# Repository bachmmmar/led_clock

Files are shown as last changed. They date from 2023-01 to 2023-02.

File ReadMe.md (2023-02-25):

This project builds a Clock with RGB LED's araged on a large circle showing current time.
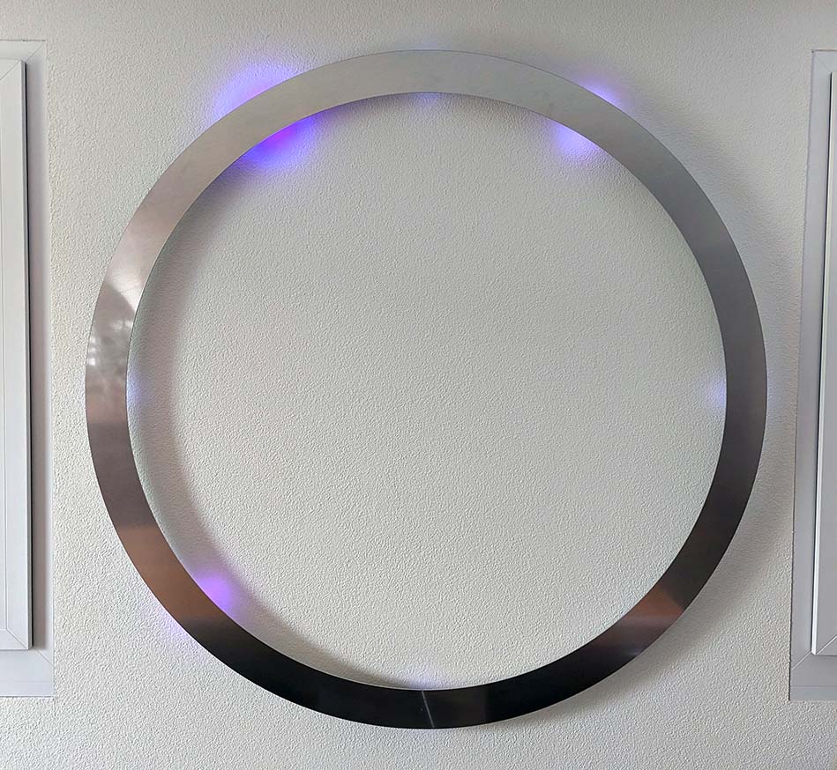
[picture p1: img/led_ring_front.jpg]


Clock showing 10:05 and 36 seconds.

It uses an Arduino Nano with Real Time Clock (RTC) and WS2811/WS2812 LED strip to display time. Ambient light sensor helps to have the right light during daytime or night.

# Overview
The images below show the main parts of the system.

| Button Mounted | Top View of Circuit | Side View of circuit |
| --- | --- | --- |
|  |  |  |

## Circuit
The following circuit was drawn with Fritzing and is located in [`circuit/led_clock.fzz`](./circuit/led_clock.fzz) folder. 
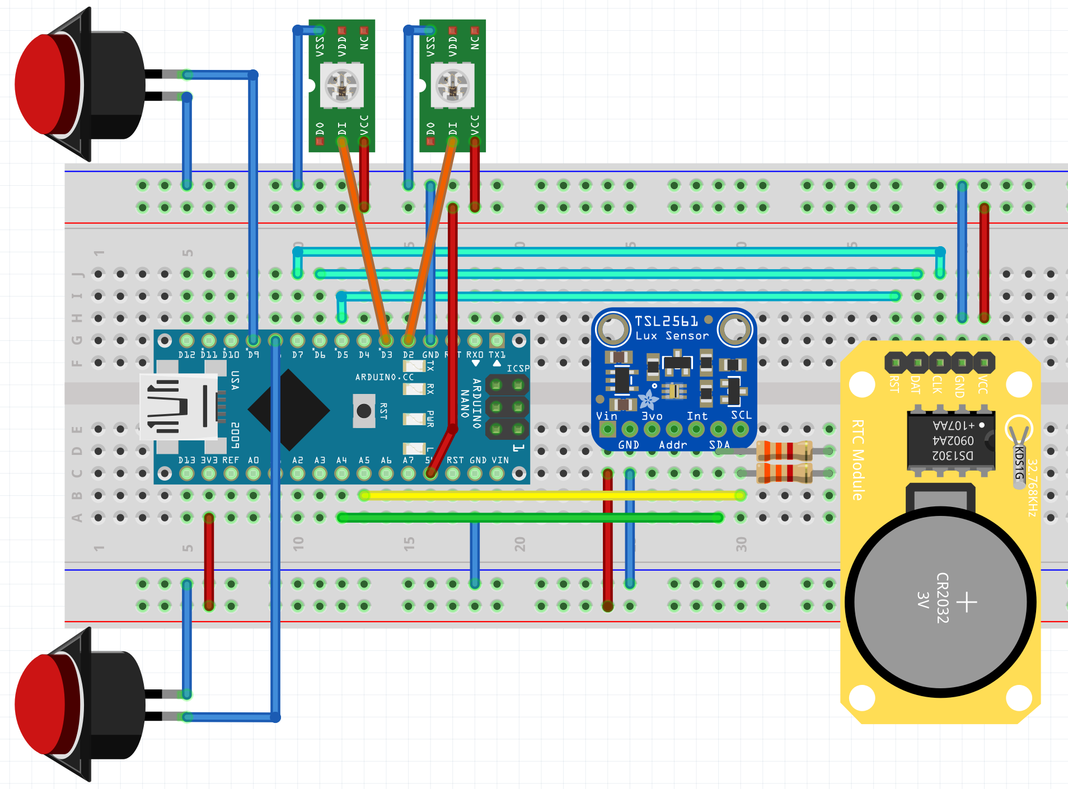
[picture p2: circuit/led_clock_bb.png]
breadboard circuit


## Mechanical Components
| Item | Supplier - Partnumber | Image | Details |
| ---  | --- | --- | --- |
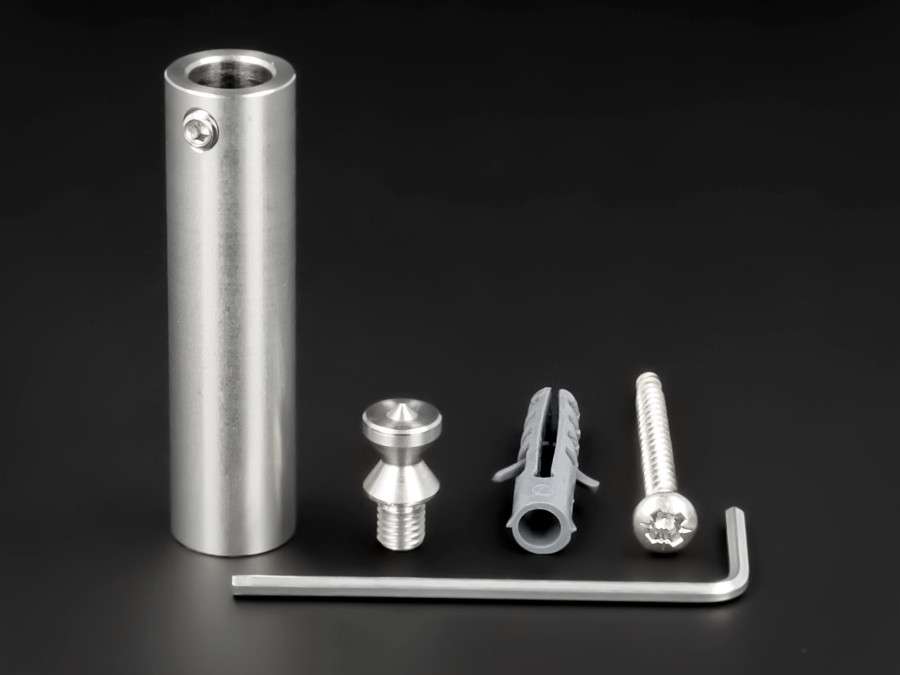
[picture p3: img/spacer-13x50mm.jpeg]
| Spacer for wall mounting | abstandshalter.com - 1.100.536 (50mm) |  | [Link](https://www.abstandshalter.com/wandabstandshalter/buchstabenbefestigung/schriften-befestigung-gewinde-edelstahl-oe-13x50mm-distanzhuelse-v2a) |
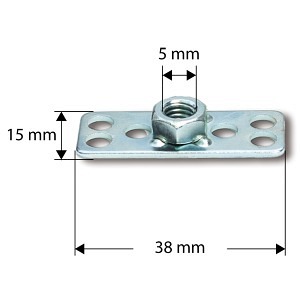
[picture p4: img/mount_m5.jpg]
| Composite mounting | Suter Kunststoffe AG - 491.5203 (15x38mm, M5) |  | [Link](https://shop.swiss-composite.ch/pi.php/Formenbau/Composite-Muttern-Schrauben/Composite-Mutter-INOX-M-5-38x15mm-pStk.html) |

## Electrical Components
| Item | Supplier - Partnumber | Image | Details |
| ---  | --- | --- | --- |
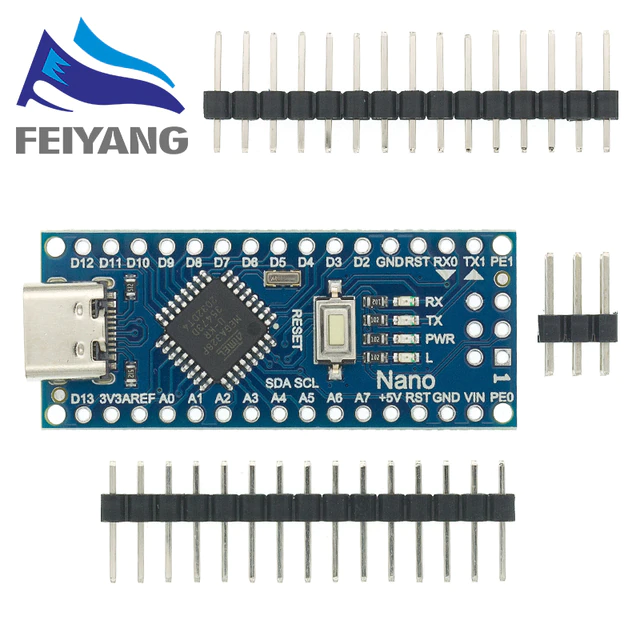
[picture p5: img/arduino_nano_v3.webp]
| Arduino Nano | Aliexpress - Arduino Nano V3.0 (ATmega328) |  | [Datasheet](datasheet/NanoV3.0_ATmega328_ali.pdf) |
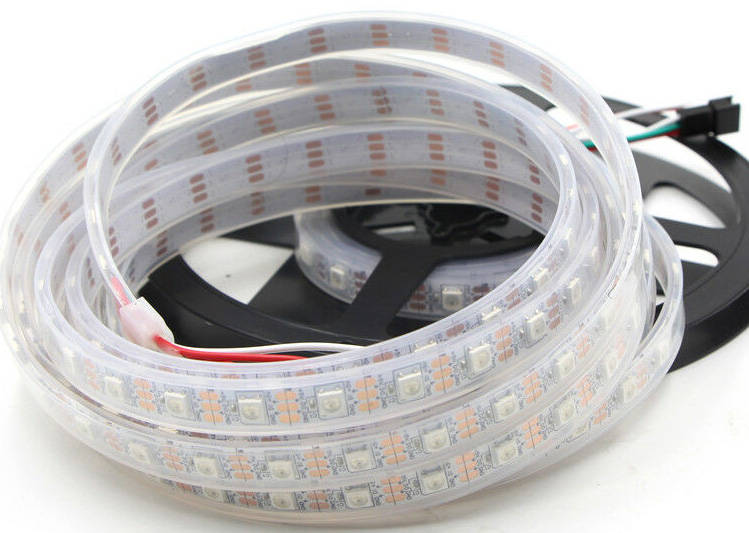
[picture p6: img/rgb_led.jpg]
| LED Stip | Aliexpress - "1m 2m 4m 5m WS2812B Led Lights WS2812 RGB Led Strip Light Individually Addressable Led Light Strip" |  | [Datasheet](datasheet/led_WS2812B.pdf)
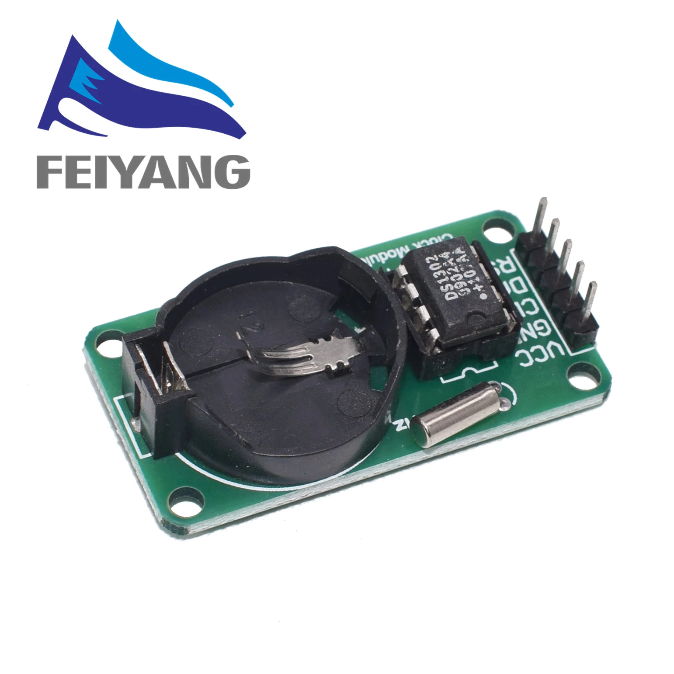
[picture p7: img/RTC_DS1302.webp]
| RTC DS1302 | Aliexpress - "RTC DS1302 Real Time Clock Modul for Arduino" |  | -
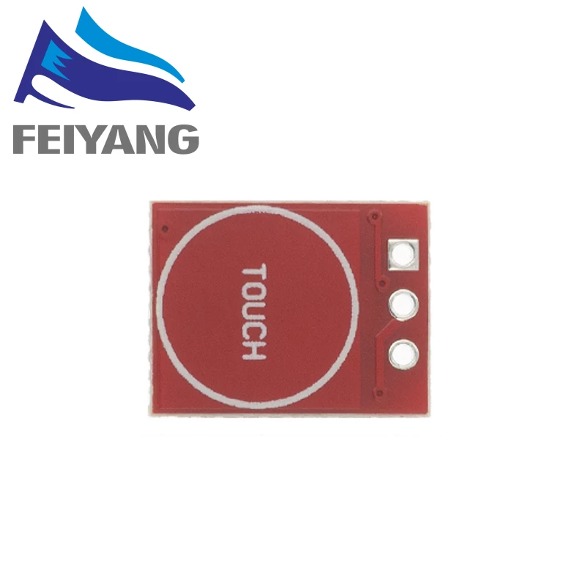
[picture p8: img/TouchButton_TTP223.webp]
| Button TTP223 | Aliexpress - "TTP223 Touch Key / Touching Button Module" |  | -
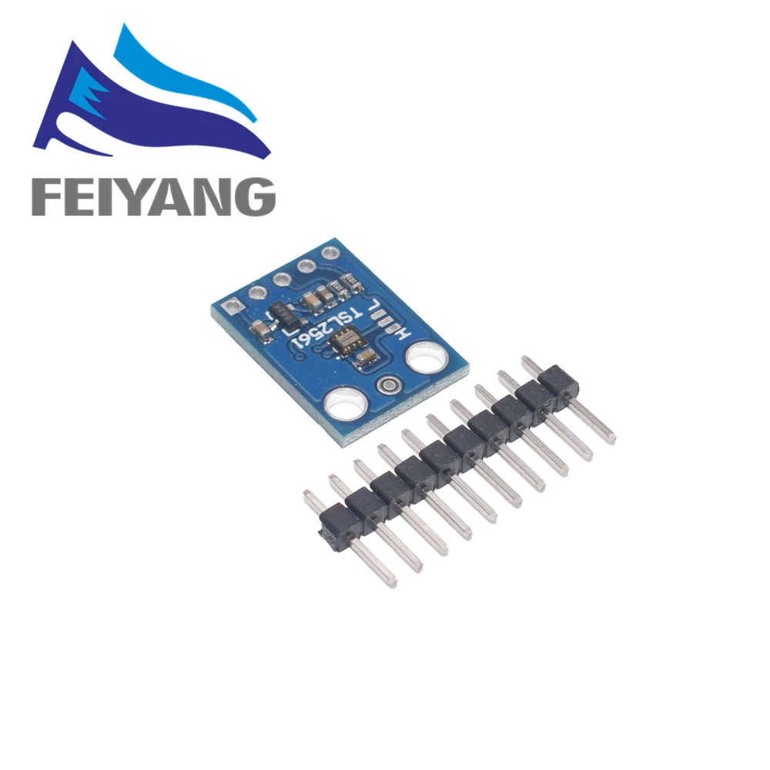
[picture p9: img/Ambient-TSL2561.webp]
| Ambient Sensor TSL2561 | Aliexpress - "GY-2561 TSL2561 Light Sensor Breakout Infrared Light Sensor Module" |  | -

## Code
The project can be compiled by using the [Arduino App](https://www.arduino.cc/download) or by using 
[CLion](https://www.jetbrains.com/clion/). This is why the project folder contains all the CMake files.

### Libraries
For controlling the LEDs, communicating with the RTC or getting ambient light the following libraries are used:
 - [TSL2561 Light Sensor](https://github.com/adafruit/TSL2561-Arduino-Library)
 - [DS1302 RTC](https://github.com/msparks/arduino-ds1302)
 - [WS2812B RGB LED](https://github.com/adafruit/Adafruit_NeoPixel)
 
 All libraries are directly located in the `src/` directory.
 
### Time Compesation
As my arduino has a verry inaccurate clock, the millis function return the wrong values.
In my case one minute tages 36'733 millis instead of 60000.
I need to multiply all millis() by 1.63

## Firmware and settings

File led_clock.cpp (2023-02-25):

#include <Arduino.h>
#include "src/clock.h"
#include "src/leds.h"
#include "src/ambient.h"


#define BUTTON_HOURS_PIN 8
#define BUTTON_MINUTE_PIN 9


Logger logger;
ClockConfig_t clk_cfg = {5, 6, 7};
Clock clk(&clk_cfg, &logger);
LedConfig_t led_cfg = {.inner_ring_pin=3, .outer_ring_pin=4,
                       .inner_ring_num_leds=229, .outer_ring_num_leds=252};
Leds led(&led_cfg, &logger);

LightSensorConfig_t light_cfg = {.tsl_i2c_addr=0x39, .update_time_ms=5000,
                                 .integration_time=TSL2561_INTEGRATIONTIME_101MS};
Ambient ambient(&light_cfg, &logger);


bool hour_pin_state, minute_pin_state;


bool isHourPinPressed() {
    return static_cast<bool>(digitalRead(BUTTON_HOURS_PIN));
}

bool isMinutePinPressed() {
    return static_cast<bool>(digitalRead(BUTTON_MINUTE_PIN));
}



/** Arduino setup function */
void setup() {
    logger.setup();
    logger.log(Logger::INFO, "Starting up clock...");

    // Configure Button Pin as input
    pinMode(BUTTON_MINUTE_PIN, INPUT_PULLUP);
    pinMode(BUTTON_HOURS_PIN, INPUT_PULLUP);

    hour_pin_state = isHourPinPressed();
    minute_pin_state = isMinutePinPressed();

    clk.setup();
    led.setup();
    ambient.setup();
}


/** Arduino loop function */
void loop() {
    clk.update();

    if (isHourPinPressed() && !hour_pin_state) {
        clk.incrementHours();
    }
    else if (isMinutePinPressed() && !minute_pin_state) {
        clk.incrementMinutes();
    }

    hour_pin_state = isHourPinPressed();
    minute_pin_state = isMinutePinPressed();

    if (ambient.update()) {
        led.updateBrightness(ambient.brightness_lux);
    }
    led.update(clk.current_time, clk.milliseconds_in_minute);
}

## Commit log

2023-01-21 Mechanical components documented and circuit drawn
    [led_clock.fzz]
2023-01-23 clock is ticking
    [led_clock.fzz]
2023-01-23 fixing button polarity
2023-01-26 Works with two LED rings and does millisecond interpolaton. Reading ambient light works as well
2023-01-29 Adjust LED brightness according to measured light intensity
2023-01-29 circuit updated
    [led_clock.fzz]
2023-02-22 adding seccond ring, but strugling on to less ram of arduino
2023-02-25 Neopixel modified to use a predefined buffer for led memory
2023-02-25 Clock working with correct milli second intterpolation
    [led_clock.cpp]
